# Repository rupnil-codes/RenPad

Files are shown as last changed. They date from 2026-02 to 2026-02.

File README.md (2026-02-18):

# RenPad
RenPad is a compact 8-key productivity macropad powered by the Seeed XIAO RP2040.  
It’s designed as a dedicated Windows control deck with an OLED status display and RGB underglow for everyday workflow speed.

---

## Features
- 8 Cherry MX mechanical keys  
- 128×32 OLED display (status + key feedback)  
- 5× SK6812MINI-E RGB LEDs  
- Seeed XIAO RP2040 microcontroller  
- KMK firmware (CircuitPython-based)  
- Fully custom PCB  
- 3D-printed case  

---

## Project Images

### Schematic
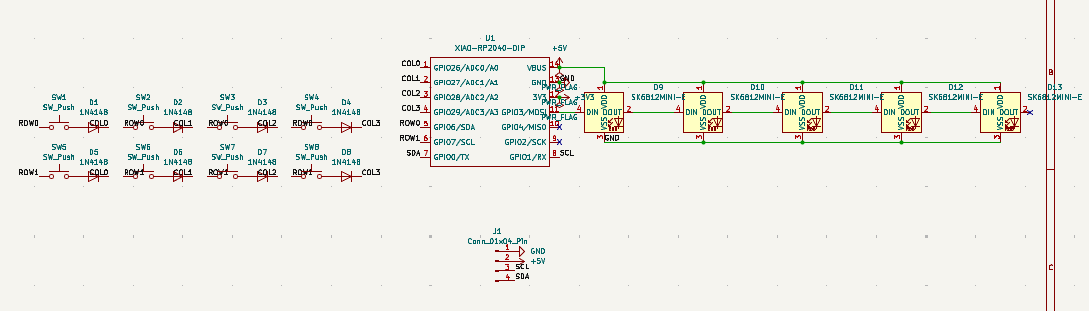
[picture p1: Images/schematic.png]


### PCB
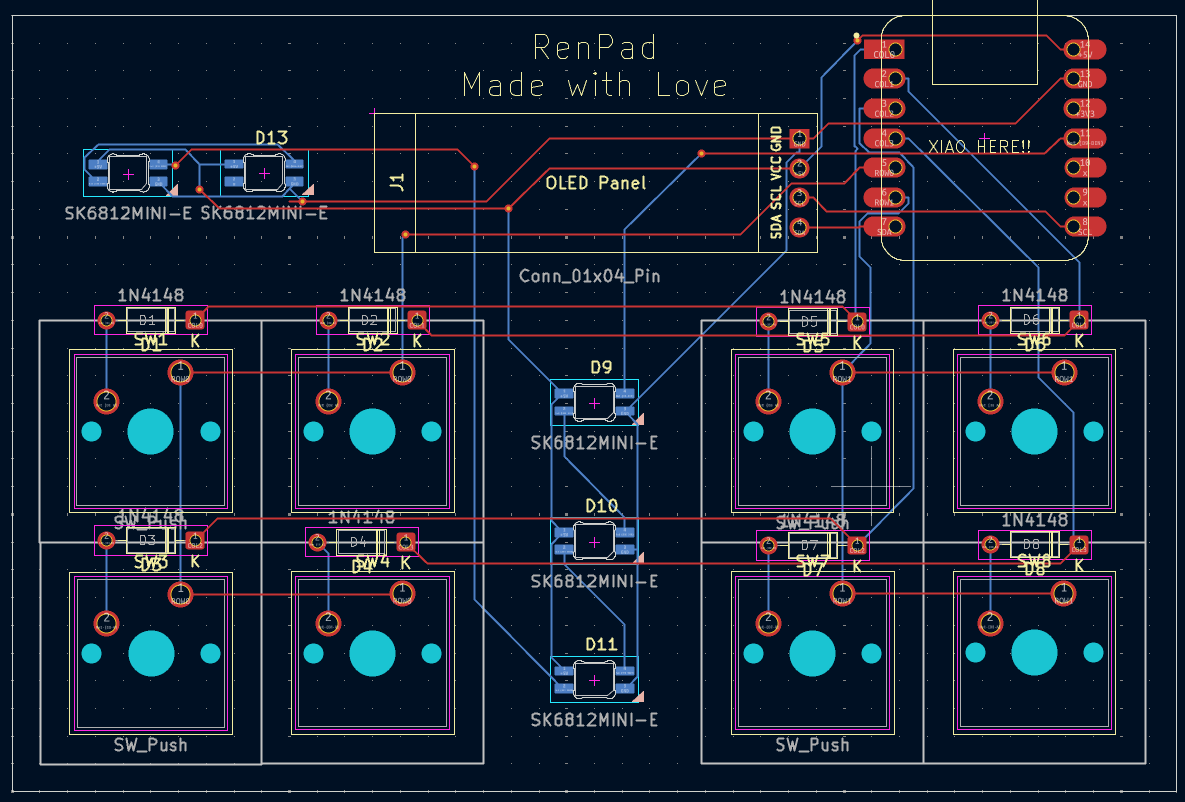
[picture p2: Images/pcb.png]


### Case Design

**Bottom Case**  
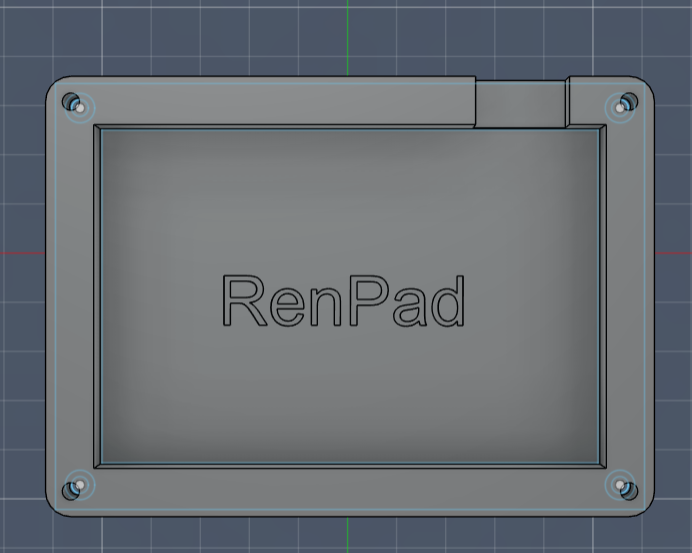
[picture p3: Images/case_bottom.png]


**Top Case**  
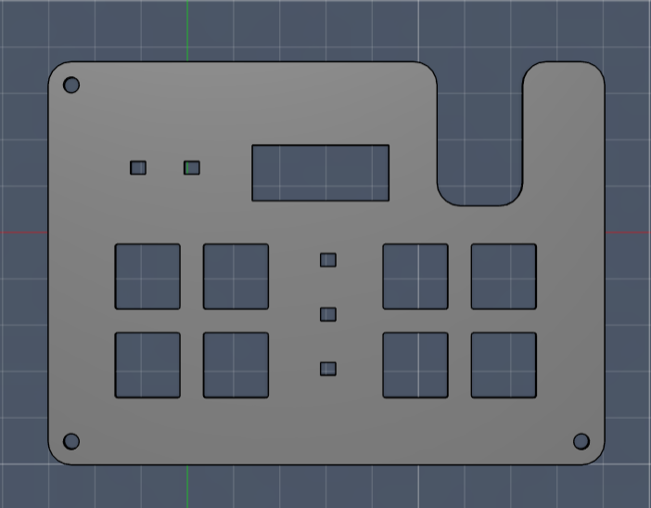
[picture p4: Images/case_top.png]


### Final Build
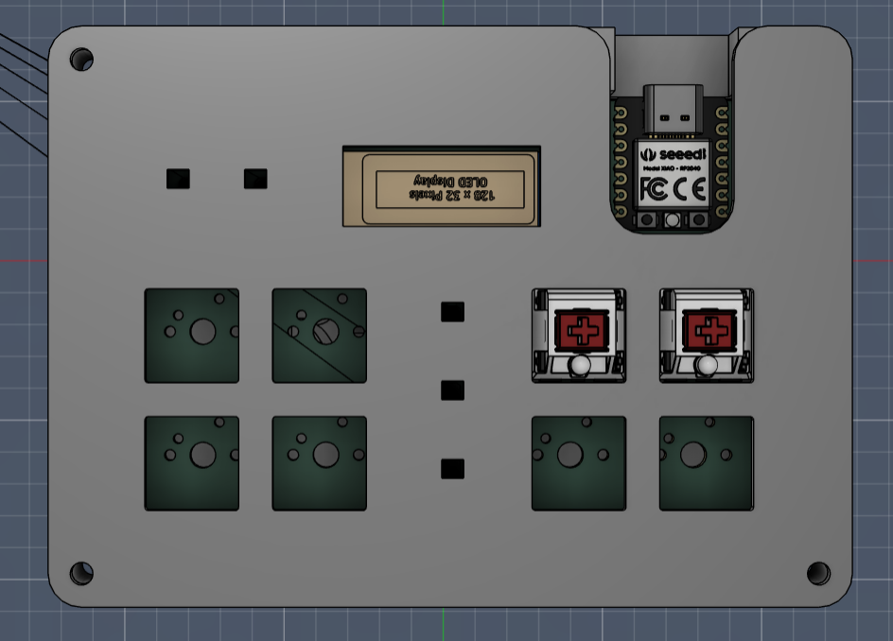
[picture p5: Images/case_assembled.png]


---

## System Overview

### MCU
Seeed Studio XIAO RP2040 (Through-hole)

### Inputs
8× Cherry MX mechanical switches

### Outputs
128×32 OLED display (I²C)  
5× SK6812MINI-E RGB LEDs  

---

## Pin Mapping

| Function | GPIO |
|---|---|
| ROW0 | GPIO6 |
| ROW1 | GPIO7 |
| COL0 | GPIO26 |
| COL1 | GPIO27 |
| COL2 | GPIO28 |
| COL3 | GPIO29 |
| RGB Data | GPIO3 |
| OLED SDA | GPIO0 |
| OLED SCL | GPIO1 |

---

## Key Layout (Windows Control Deck)

| Key | Shortcut | Function |
|---|---|---|
| K1 | Win + V | Clipboard history |
| K2 | Alt + Tab | Switch apps |
| K3 | Win + Tab | Task view |
| K4 | Win + E | File Explorer |
| K5 | Ctrl + Shift + Esc | Task Manager |
| K6 | Win + Ctrl + D | New virtual desktop |
| K7 | Win + Ctrl + ← | Desktop left |
| K8 | Win + Ctrl + → | Desktop right |

---

## Bill of Materials (BOM)

| Part | Quantity | Manufacturer | Part Number |
|---|---|---|---|
| Seeed XIAO RP2040 (TH) | 1 | Seeed Studio | 102010428 |
| Cherry MX Mechanical Switch | 8 | Cherry | MX Series |
| 1N4148 Diodes (TH) | 8 | Vishay | 1N4148 |
| SK6812MINI-E LEDs | 5 | WorldSemi | SK6812MINI-E |
| 128×32 OLED Display | 1 | Generic | SSD1306 |
| DSA Keycaps | 8 | Generic | DSA Blank |
| M3 Screws | 4 | Generic | M3 |
| Heatset Inserts | 4 | Generic | M3 |

---

## Firmware
RenPad runs on **KMK (CircuitPython)** firmware.

The firmware supports:
- Key matrix scanning  
- OLED key feedback display  
- RGB underglow effects  
- Windows productivity shortcuts  

Firmware is located in the **Firmware/** folder.

---

## Case
The enclosure is fully 3D-printed and designed in Fusion 360.

It consists of:
- Bottom shell  
- Top plate  
- Heatset insert mounts  

Exported as STEP files in the **CAD/** folder.

---

## Author
Designed and built by **Rupnil.Codes**
Hack Club Hackpad Project
```

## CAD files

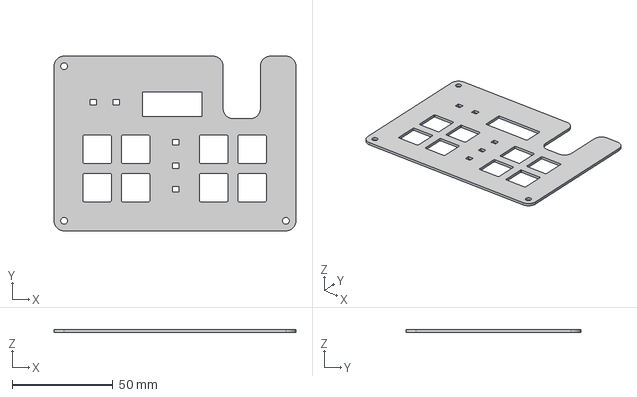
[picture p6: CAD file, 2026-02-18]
CAD/RenPad Top.step.step
120.0 x 86.7 x 1.50 mm

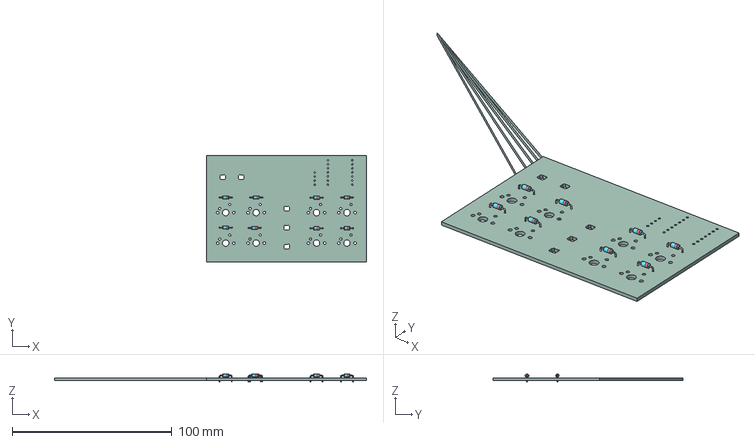
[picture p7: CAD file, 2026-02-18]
PCB/RenPad.step
195.3 x 119.1 x 5.01 mm
D_DO-35_SOD27_P7.62mm_Horizontal x 8
RenPad_PCB

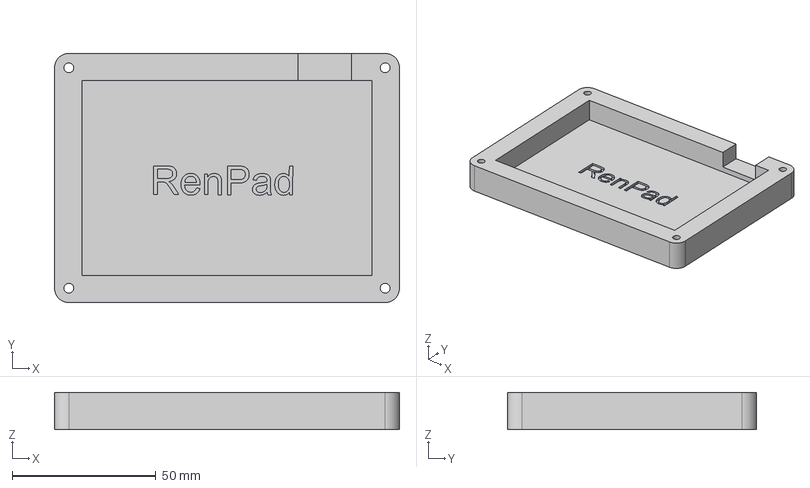
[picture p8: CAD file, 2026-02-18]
CAD/RenPad Base.step.step
120.0 x 86.7 x 13.0 mm

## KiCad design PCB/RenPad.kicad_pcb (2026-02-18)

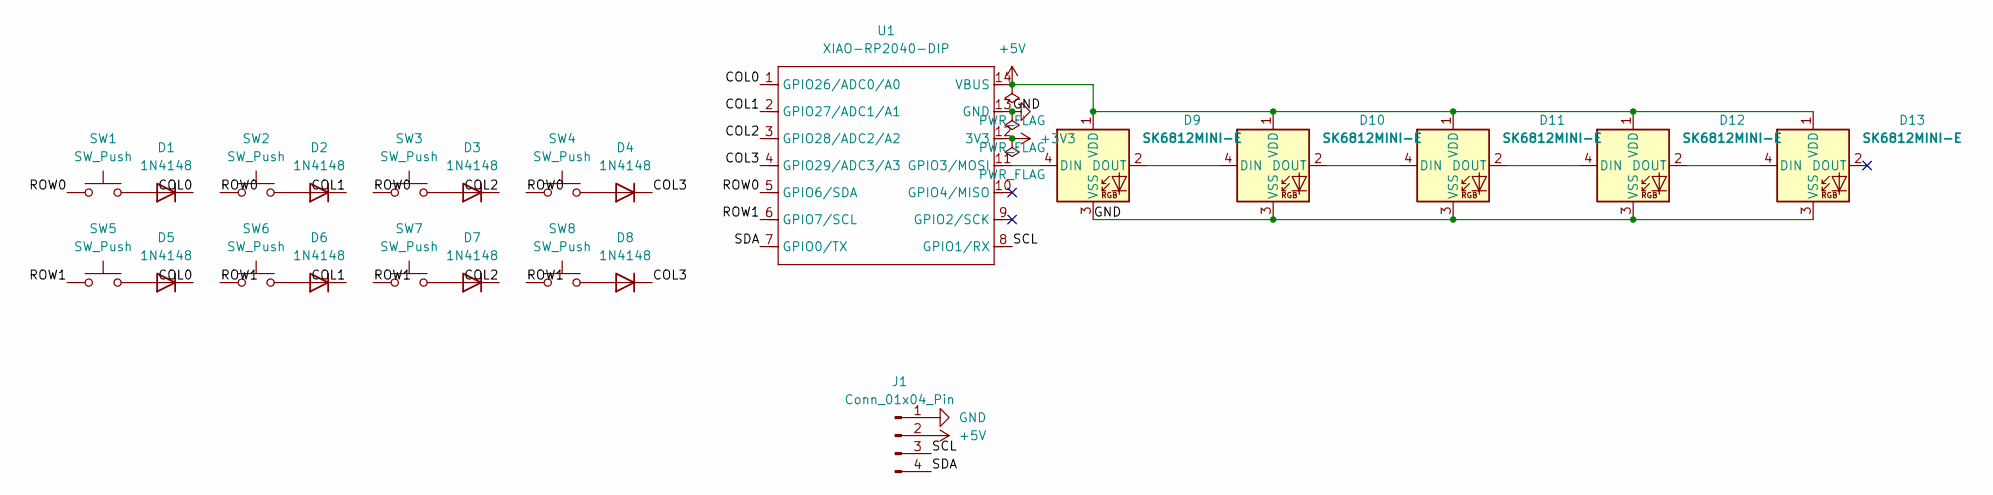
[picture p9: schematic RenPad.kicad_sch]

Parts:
D1, D2, D3, D4, D5, D6, D7, D8: 1N4148; D_DO-35_SOD27_P7.62mm_Horizontal
D9, D10, D11, D12, D13: SK6812MINI-E; SK6812MINI-E_fixed
J1: Conn_01x04_Pin; SSD1306-0.91-OLED-4pin-128x32
SW1, SW2, SW3, SW4, SW5, SW6, SW7, SW8: SW_Push; SW_Cherry_MX_1.00u_PCB
U1: XIAO-RP2040-DIP; XIAO-Generic-Hybrid-14P-2.54-21X17.8MM

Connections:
+3V3: U1.12 (3V3)
+5V: D9.1 (VDD), D10.1 (VDD), D11.1 (VDD), D12.1 (VDD), D13.1 (VDD), J1.2, U1.14 (VBUS)
/COL0: D1.1 (K), D5.1 (K), U1.1 (GPIO26/ADC0/A0)
/COL1: D2.1 (K), D6.1 (K), U1.2 (GPIO27/ADC1/A1)
/COL2: D3.1 (K), D7.1 (K), U1.3 (GPIO28/ADC2/A2)
/COL3: D4.1 (K), D8.1 (K), U1.4 (GPIO29/ADC3/A3)
/ROW0: SW1.1, SW2.1, SW3.1, SW4.1, U1.5 (GPIO6/SDA)
/ROW1: SW5.1, SW6.1, SW7.1, SW8.1, U1.6 (GPIO7/SCL)
/SCL: J1.3, U1.8 (GPIO1/RX)
/SDA: J1.4, U1.7 (GPIO0/TX)
GND: D9.3 (VSS), D10.3 (VSS), D11.3 (VSS), D12.3 (VSS), D13.3 (VSS), J1.1, U1.13 (GND)
unnamed: D1.2 (A), SW1.2
unnamed: D2.2 (A), SW2.2
unnamed: D3.2 (A), SW3.2
unnamed: D4.2 (A), SW4.2
unnamed: D5.2 (A), SW5.2
unnamed: D6.2 (A), SW6.2
unnamed: D7.2 (A), SW7.2
unnamed: D8.2 (A), SW8.2
unnamed: D9.4 (DIN), U1.11 (GPIO3/MOSI)
unnamed: D9.2 (DOUT), D10.4 (DIN)
unnamed: D10.2 (DOUT), D11.4 (DIN)
unnamed: D11.2 (DOUT), D12.4 (DIN)
unnamed: D12.2 (DOUT), D13.4 (DIN)

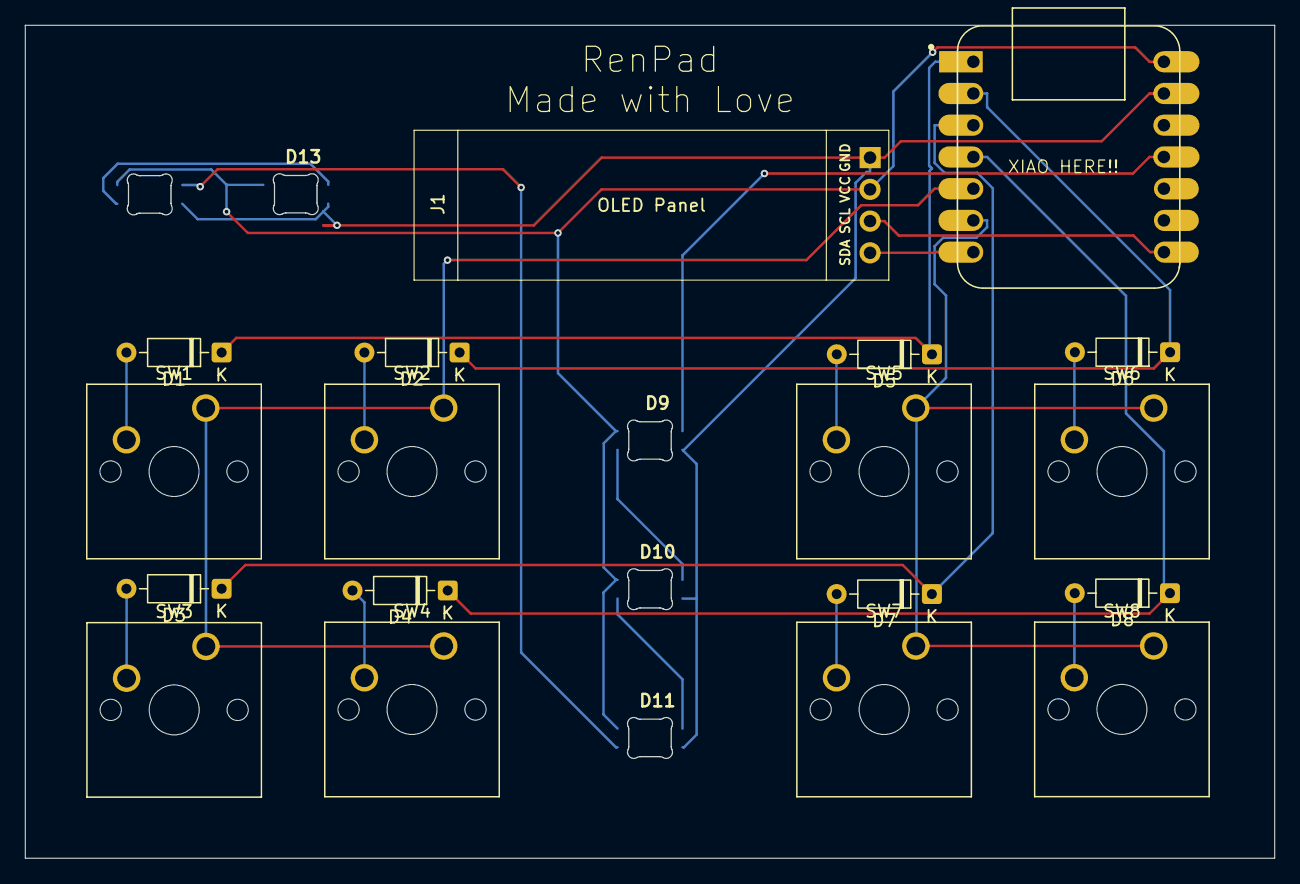
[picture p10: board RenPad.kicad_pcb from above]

Board: 2 copper layers, 100.0 x 66.7 mm, 23 parts (0 on the bottom side), 23 nets.

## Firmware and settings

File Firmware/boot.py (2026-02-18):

import time
import board
import busio
import usb_hid
import storage
import supervisor
import displayio
import adafruit_ssd1306

from kmk.kmk_keyboard import KMKKeyboard
from kmk.keys import KC
from kmk.scanners import DiodeOrientation
from kmk.extensions.rgb import RGB
from kmk.extensions.display import Display, TextEntry

usb_hid.enable((
    usb_hid.Device.KEYBOARD,
    usb_hid.Device.CONSUMER_CONTROL,
))

storage.remount("/", readonly=False)

supervisor.set_usb_identification(
    manufacturer="Rz3neri",
    product="RenPad"
)

keyboard = KMKKeyboard()

keyboard.col_pins = (board.GP26, board.GP27, board.GP28, board.GP29)
keyboard.row_pins = (board.GP6, board.GP7)
keyboard.diode_orientation = DiodeOrientation.ROW2COL

rgb = RGB(
    pixel_pin=board.GP3,
    num_pixels=5,
    hue_default=170,
    sat_default=255,
    val_default=80,
)
keyboard.extensions.append(rgb)

displayio.release_displays()
i2c = busio.I2C(board.GP1, board.GP0)
oled = adafruit_ssd1306.SSD1306_I2C(128, 32, i2c, addr=0x3C)

last_key = ""
last_key_time = 0
DISPLAY_TIME = 3

def key_text():
    if time.monotonic() - last_key_time < DISPLAY_TIME:
        return last_key
    return ""

display = Display(
    display=oled,
    entries=[
        TextEntry(text="RenPad", x=0, y=0),
        TextEntry(text=key_text, x=0, y=16),
    ],
)
keyboard.extensions.append(display)

keyboard.keymap = [[
    KC.LGUI(KC.V),
    KC.LALT(KC.TAB),
    KC.LGUI(KC.TAB),
    KC.LGUI(KC.E),

    KC.LCTL(KC.LSHIFT(KC.ESC)),
    KC.LGUI(KC.LCTL(KC.D)),
    KC.LGUI(KC.LCTL(KC.LEFT)),
    KC.LGUI(KC.LCTL(KC.RIGHT)),
]]

key_names = {
    keyboard.keymap[0][0]: "Clipboard",
    keyboard.keymap[0][1]: "Switch App",
    keyboard.keymap[0][2]: "Task View",
    keyboard.keymap[0][3]: "Explorer",
    keyboard.keymap[0][4]: "TaskMgr",
    keyboard.keymap[0][5]: "New Desk",
    keyboard.keymap[0][6]: "Desk Left",
    keyboard.keymap[0][7]: "Desk Right",
}

@keyboard.before_hid_send
def show_pressed_key(keyboard):
    global last_key, last_key_time
    if keyboard.keys_pressed:
        key = list(keyboard.keys_pressed)[0]
        if key in key_names:
            last_key = key_names[key]
        else:
            last_key = "Key"
        last_key_time = time.monotonic()

@keyboard.after_hid_send
def react_to_keys(keyboard):
    if keyboard.keys_pressed:
        rgb.increase_hue()

keyboard.go()
